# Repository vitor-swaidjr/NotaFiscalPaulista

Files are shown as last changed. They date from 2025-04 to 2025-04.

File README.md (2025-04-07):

# NotaFiscalPaulista
Projeto que cria um dispositivo (hardware) e app para Android para auxiliar ONGs a cadastrar notas fiscais para ajudar na captação de recursos.

Este projeto é constituído de um hardware usando arduino pro mini versão Leonardo ou compatível com processador Atmega32u4, um módulo bluetooth hc-05, hc-06 ou similar e um app que interpreta os qrcodes dos cupons fiscais. Após a leitura sem erro e interpretação, o código de 44 digitos é separado e enviado do APP para o hardware que vai atuar como um teclado e um mouse. Após o envio dos 44 dígitos é enviado um ENTER e um clique para auxiliar na operação com o site da [Nota Fiscal Paulista](https://www.nfp.fazenda.sp.gov.br/Inicio.aspx).

Este projeto pode ser adaptado para qualquer sistema similar de outros estados.

# Construção do hardware
Por definição o hardwware consta de uma placa Arduino pro mini com micro-controlador Atmega32u4 que recebe alimentação e faz comunicação com o PC Windows ou Linux. Por definição também os pinos 8 e 9 do Arduino são ligados no módulo bluetooth conforme lista abaixo:

<table>
  <thead>
    <td>Arduino</td><td>Módulo Bluetooth</td>
  </thead>
  <tbody>
    <tr><td>pin 8 (TX)</td><td>RX</td></tr>
    <tr><td>pin 9 (RX)</td><td>TX</td></tr>
    <tr><td>VCC</td><td>VCC</td></tr>
    <tr><td>GND</td><td>GND</td></tr>
  </tbody>
</table>

OBS.: verifique a tensão de cada módulo para evitar queima do componente.

Nos sites abaixo é possível encontrar tutoriais de como mudar o nome do seu módulo Bluetooth (sugestão: use TECLADONFP):

https://www.martyncurrey.com/hc-06-hc01-comv2-0/

https://www.youtube.com/watch?app=desktop&v=s-lzV_RfZoo - para modulo JDY-31

A montagem cabe numa caixinha plástica de pelo menos 6 x 4 x 2 cm. É preciso realizar furações para export os leds e o conector usb da placa Arduino.

Um cabo micro usb ou usb-c é necessário para ligar o arduino ao pc/notebook.

# Firmware
Como a comunicação serial nativa do Arduino é usada para comunicar com o PC, a solução é usar o pacote SoftSerial para usar os pinos 8 e 9 como uma interface serial para comunicar  com o módulo Bluetooth. Os pinos 8 e 9 foram usados por definição neste projeto, porém poderiam ser utilizados outros. No site da [documentação do Arduino](https://docs.arduino.cc/libraries/) procure por SoftwareSerial para mais detalhes. Também são utilizadas bibliotecas Mouse e Keyboard que fazem parte da distribuição padrão da Arduino IDE.

Baixe a [IDE Arduino](https://www.arduino.cc/en/software#ide), instale e execute conforme as instruções no site, baixe o arquivo TecladoViaBluetooth.ino deste projeto e abra na IDE. Plugue o cabo usb no seu pc/notebook e na placa Arduino. Na IDE em Tools/Ferramentas selecione a placa Arduino Leonardo e em Port/Porta selecione a COMx (x é o número que o Windows atribui) ou /dev/ttyUSBy (y é o número que o LInux atribui). Em seguida clique no botão de upload/carregar o programa. 

# App Android
Para desenvolver o APP para Android foi utilizado o site https://appinventor.mit.edu que possui uma interface intuitiva e amigável para desenvolver e prototipar APPs para Android.

Clique no link anterior e faça o cadastro de uma conta para você. Em seguida clique no link da [Galeria de Aplicativos do App Inventor](https://gallery.appinventor.mit.edu/?galleryid=56ef07f5-e61f-4e7a-90a5-a4fdf5190a5d) e baixe o app na sua conta clicando em "Load App Into MIT App Inventor" ou "Load App Into MIT App Inventor". Vai aparecer uma tela com o nome CadastraNFP. Clique nesse nome e em seguida no topo da página procure por Build/Constriur e clique em Android Package (apk). Aguarde a compilação e baixe para seu celular conforme as instruções que vão aparecer na tela. 

# Operação
Após baixar o APP em [Galeria de Aplicativos do App Inventor](https://gallery.appinventor.mit.edu/?galleryid=56ef07f5-e61f-4e7a-90a5-a4fdf5190a5d) basta instalar no Celular Android. Forneça as permissões de uso da câmera e autorize fontes desconhecidas. Rode as rotinas de scan do seu aparelho para garantir a segurança. Este aplicativo NÃO coleta estatísticas ou dados de uso.

Considerando que o hardware já foi construído, ligue o harware no seu note e faça o pareamento do bluetooth do seu celular com o TECLADONFP.

Abra o APP e clique no botão de baixo para conectar no disposivo correto. Na lista que vai aparecer procure por TECLADONFP ou o nome que você utilizou.

Abra o site da [Nota Fiscal Paulista](https://www.nfp.fazenda.sp.gov.br/Inicio.aspx) e vá em Entidades -> Cadastrar Cupons. Na interface de entrada de cupons clique no campo chave de acesso e deixe o mouse posicionado no início desse campo. Após ler um QRCODE o mesmo será enviado para o notebook e se o mouse estiver posicionado no local correto o próximo código já pode ser lido, acelerando o processo.

## Bons cadastros.

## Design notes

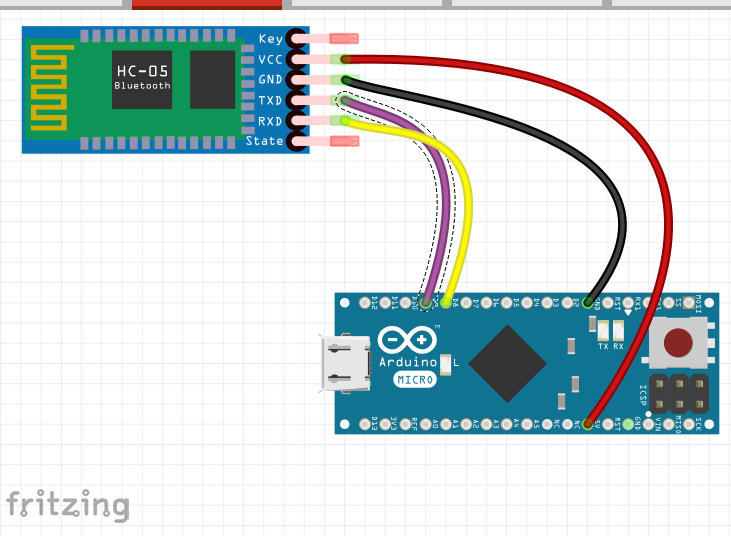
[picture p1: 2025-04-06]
Hardware/Diagramas/TecladoNFP-Ligação dos fios.png

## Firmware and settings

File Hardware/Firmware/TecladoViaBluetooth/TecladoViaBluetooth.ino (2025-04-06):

#include <Mouse.h>
#include <Keyboard.h>
#include <SoftwareSerial.h>

#define BTtx 8
#define BTrx 9

//https://www.martyncurrey.com/hc-06-hc01-comv2-0/
//https://www.youtube.com/watch?app=desktop&v=s-lzV_RfZoo - para modulo JDY-31

SoftwareSerial BT(BTrx, BTtx);

void setup(){
  pinMode(BTrx, INPUT);
  pinMode(BTtx, OUTPUT);
  BT.begin(9600);
  delay(500);
  Mouse.begin();
  delay(500);
  Keyboard.begin();
  delay(500);
  Serial.begin(9600);
  delay(500);
}
char c =' ';
int count = 0;

void loop(){
  if (count == 0 ){
    delay(1000);
    Mouse.click();
    count++;
    Serial.println("posição enviada");
  }
  if(BT.available()){
    //Serial.print(".");
    c=BT.read();
    if (c == '^'){
      Keyboard.println("");
      Serial.println(c);
      count++;
      if (count>=2){
        count=0;
      }
    }
    else {
      Keyboard.write(c);
      Serial.print(c);
    }
    //count++;
    //if (count==44){
    //  Keyboard.println("");
    //  count=0;
 
  }
  // if(Serial.available()){
  //   c=Serial.read();  
  //   Serial.write(c);
  //   BT.write(c);
  // }
  delay(2);
}

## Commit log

2025-04-06 Upload do projeto e instruções de uso
    [TecladoNFP-Ligação dos fios.fzz]
2025-04-06 correção no diagrama do fritzing
    [TecladoNFP-Ligação dos fios.fzz]
